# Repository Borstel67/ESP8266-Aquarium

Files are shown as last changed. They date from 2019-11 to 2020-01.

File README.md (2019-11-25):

# esp8266-Aquarium

Beschreibung Projekt

Mit diesem Projekt habe ich meine Aquarien Beleuchtung auf LED Umgestellt.

Die Aquarien Beleuchtungssteuerung basiert auf einem ESP8266 und einem WS2812b Led Strip.
Der ESP übernimmt dabei die Ansteuerung des Strips und beinhaltet den Webserver mit der Bedienoberfläche zur Anzeige der Zustände
und Konfiguration der Beleuchtung.

Funktionen:
-	WLAN
1.	Config Mode
2.	AP Mode
3.	STA Mode

-	Uhr
1.	Synchronisation mit NTP Server
2.	Zeitzonen Einstellung Uhr
3.	Manuelle Zeiteinstellung
4.	Sommer Winterzeit Umschaltung Uhr

-	Sonne und Mond
1.	Sonnenaufgangs und Sonnenuntergangs Berechnung
2.	Mondphasen Berechnung zur Ansteuerung eines Teiles des Strip für die Mondbeleuchtung

-	Steuerung
1.	Für jede 4te LED (4 Kanäle) kann eine andere Farbe für Tag und Nacht vorgewählt werden 
2.	Jeder Kanal hat zwei Schulzeiten 
3.	Die maximale Anzahl der des LED Strip kann eingestellt werden
4.	Für die Mondbeleuchtung können beliebige LED ausgewählt werden

-	Eingebundenen Protokolle
1.	Syslog
2.	FTP
3.	telnet

-	Konfiguration und Bedienung
1.	Die Konfiguration erfolgt über den Integrierten WEB- Server
2.	Die Konfigurationsdaten werden in einen JSON File auf dem ESP abgelegt.

Offen Punkte 
-	UDP Kopplung mehrerer ESP zur Ansteuerung weiteren Geräten wie CO2 Generator
-	HomeMatic Kopplung
-	MQTT Einbindung

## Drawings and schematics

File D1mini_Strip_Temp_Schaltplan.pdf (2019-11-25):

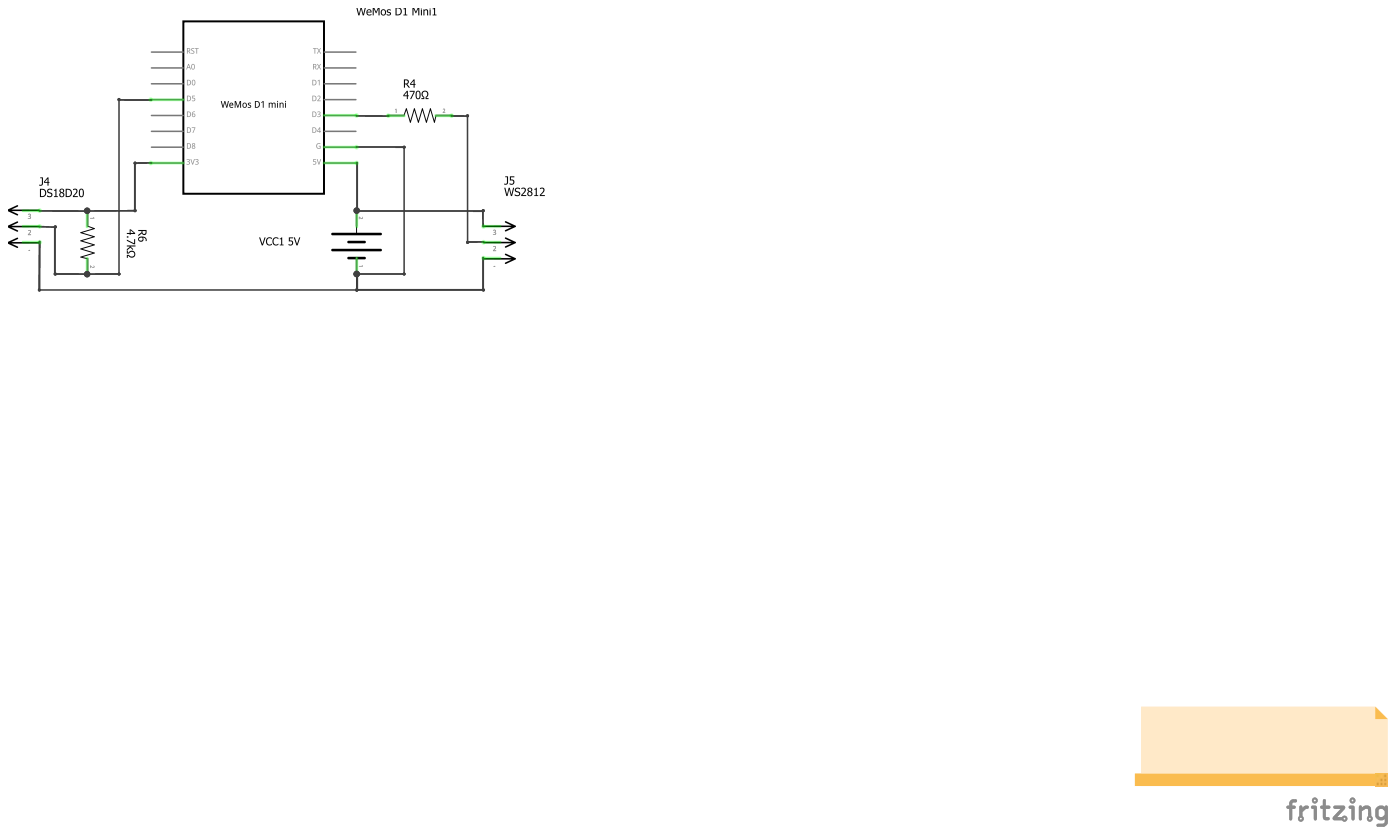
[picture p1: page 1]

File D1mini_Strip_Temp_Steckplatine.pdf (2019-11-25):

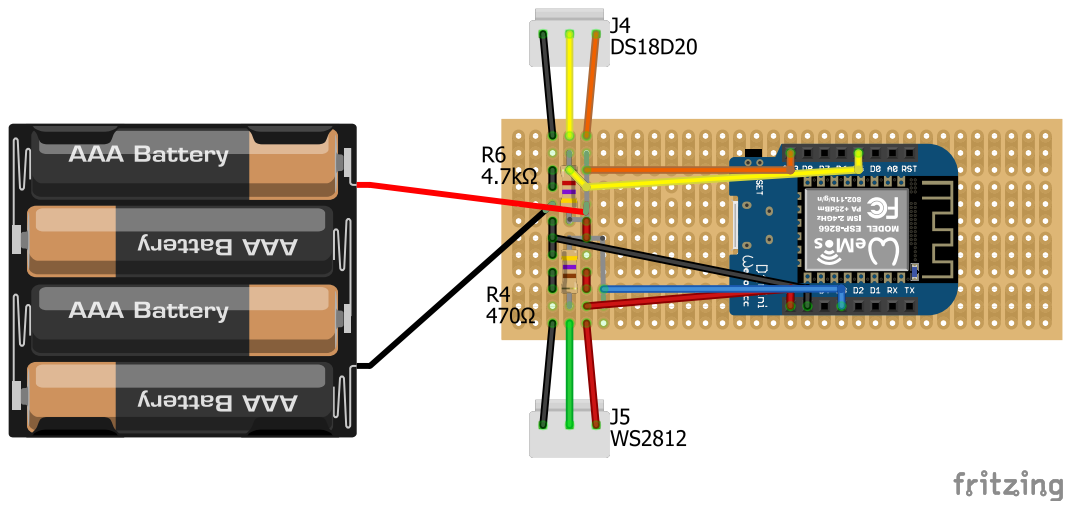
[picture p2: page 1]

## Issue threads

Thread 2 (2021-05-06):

RGB bzw BGR

Faabu, 2021-05-06:
Ist es möglich die Art des LED Strips zu ändern ?? Habe schon versucht das in der Aquarium .ino zu ändern,leider scheitert es beim kompillieren mit Arduino ide oder VC Code bei mir

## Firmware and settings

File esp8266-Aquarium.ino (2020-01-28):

/*
  ESP8266 Bibliotek 2.4.1
  ArduinoJson.h version 5
  Generic ESP8285 Module
  Flash Mode: DOUT
  Flash Frequency: 40 MHz
  CPU Frequency: 80 MHz
  Flash Size: 1M (64k SPIFFS)
*/

#define VARSIZE4				4
#define VARSIZE6				6
#define VARSIZE8				8
#define VARSIZE10				10
#define VARSIZE16				16
#define VARSIZE32	    		32
#define VARSIZE64	    		64
#define VARSIZE255	    		255


#define FASTLED_ALLOW_INTERRUPTS 0

#include <Arduino.h>
#include <FS.h>
#include <ArduinoJson.h>				// v.5.xx
#include <ESP8266WiFi.h>
#include <ESP8266FtpServer.h>
#include <ESP8266HTTPClient.h>
#include <ESP8266WebServer.h>
#include <ESP8266HTTPUpdateServer.h>
#include <ESP8266mDNS.h>
#include <uMQTTBroker.h>
#include <PubSubClient.h>
#include <sunMoon.h>
#include <Time.h>						// für NTP
#include <Timezone.h>					// sommer winterzeit
#include <TimeLib.h>					// für NTP und SunMoon
#include <ArduinoOTA.h>
#include <WiFiUdp.h>
#include <FastLED.h>
#include <OneWire.h>				// für Temperatur DS18B20
#include <DallasTemperature.h>		// für Temperatur DS18B20
#include "WM.h"
#include "css_global.h"
#include "js_global.h"
#include "js_webled.h"
#include "js_fwupd.h"

// definire Programmteile
// def Debug Serial ein und ausschalten
#define	LEDStrip // definierung wenn ein LEDStrip angeschlossen
//#define UDPDEBUG
#define SERIALDEBUG
#define TELNET

// definire Parameter 
#define MillisKeyBounce			100		//Millisekunden zwischen 2xtasten
#define ConfigPortalTimeout		180		//Timeout (Sekunden) des AccessPoint-Modus
#define HTTPTimeOut				1500	//Timeout (Millisekunden) für http requests
#define UDPPORT					6676	// UDP Port
#define KEYPRESSLONGMILLIS		1500	//Millisekunden für langen Tastendruck bei Sonoff Touch als Sender
#define MAX_TELNET_CLIENTS		2		// Telnet Server

const String FIRMWARE_VERSION = "1.3.5";


//FW über GITHUB
const char GITHUB_REPO_URL[] PROGMEM = "https://api.github.com/repos/jp112sdl/SonoffHMLOX/releases/latest";

//Debug Syslog über UDP
#ifdef UDPDEBUG
const char* SYSLOGIP = "192.168.178.100";
#define SYSLOGPORT          514
#endif
enum _SyslogSeverity {
	_slEmergency,
	_slAlert,
	_slCritical,
	_slError,
	_slWarning,
	_slNotice,
	_slInformational,
	_slDebug
};
// end Debug

//Auswahl Homatic Loxon
enum BackendTypes_e {
	BackendType_HomeMatic,
};

enum TransmitStates_e {
	NO_TRANSMITSTATE,
	TRANSMITSTATE
};

// Golbal Config schreiben in Datei jonson.conf
struct globalconfig_t {
	char ledcolor1[VARSIZE8] = "#ffffff";				// Color Kanal 1 Ein
	char ledcolor2[VARSIZE8] = "#ffff00";				// Color Kanal 2 Ein
	char ledcolor3[VARSIZE8] = "#ccff00";				// Color Kanal 3 Ein
	char ledcolor4[VARSIZE8] = "#ffa200";				// Color Kanal 4 Ein
	char ledcolor5[VARSIZE8] = "#000000";				// Color Kanal 1 Aus
	char ledcolor6[VARSIZE8] = "#000000";				// Color Kanal 2 Aus
	char ledcolor7[VARSIZE8] = "#000000";				// Color Kanal 3 Aus
	char ledcolor8[VARSIZE8] = "#000000";				// Color Kanal 4 Aus
	char ledcolormoon[VARSIZE8] = "#000000";			// Color bei Mond
	char time1[VARSIZE6] = "06:30";						// Zeit Kanal 1 Ein
	char time11[VARSIZE6] = "00:00";					// Zeit Kanal 1 Ein
	char time2[VARSIZE6] = "06:45";						// Zeit Kanal 2 Ein
	char time21[VARSIZE6] = "00:00";					// Zeit Kanal 2 Ein
	char time3[VARSIZE6] = "06:15";						// Zeit Kanal 3 Ein
	char time31[VARSIZE6] = "00:00";					// Zeit Kanal 3 Ein
	char time4[VARSIZE6] = "06:30";						// Zeit Kanal 4 Ein
	char time41[VARSIZE6] = "00:00";					// Zeit Kanal 4 Ein
	char time5[VARSIZE6] = "21:00";						// Zeit Kanal 1 Aus
	char time51[VARSIZE6] = "00:00";					// Zeit Kanal 1 Aus
	char time6[VARSIZE6] = "21:00";						// Zeit Kanal 2 Aus
	char time61[VARSIZE6] = "00:00";					// Zeit Kanal 2 Aus
	char time7[VARSIZE6] = "21:30";						// Zeit Kanal 3 Aus
	char time71[VARSIZE6] = "00:00";					// Zeit Kanal 3 Aus
	char time8[VARSIZE6] = "21:45";						// Zeit Kanal 4 Aus
	char time81[VARSIZE6] = "00:00";					// Zeit Kanal 4 Aus
	char hk1[VARSIZE4] = "2";							// Hand Kanal 1 (0=Aus/1=Ein/2=Uhr)
	char hk2[VARSIZE4] = "2";							// Hand Kanal 2 (0=Aus/1=Ein/2=Uhr)
	char hk3[VARSIZE4] = "2";							// Hand Kanal 3 (0=Aus/1=Ein/2=Uhr)
	char hk4[VARSIZE4] = "2";							// Hand Kanal 4 (0=Aus/1=Ein/2=Uhr)
	char hkm[VARSIZE4] = "2";							// Hand Kanal M (0=Auto/1=Ein/2=Uhr)
	char ledanzges[VARSIZE4] = "221";					// Anzahl LED in Strip
//	char ledanzges[VARSIZE4] = "76";					// Anzahl LED in Strip
	char ledanzmond[VARSIZE255] = "37-48;67-78;107-118";// Anzahl der mond led
//	char ledanzmond[VARSIZE255] = "54-56";              // Anzahl der mond led
	char ledanzcol[VARSIZE4] = "4";						// Anzahl der Collorkanäle
	char latitude[VARSIZE10] = "50.92878";				// Jena cordinates
	char longtitude[VARSIZE10] = "11.5899";
	//char DevicAPName[VARSIZE32] = "AP_TEST";			// Name des Access Point
	byte BackendType = BackendType_HomeMatic;			// definierung des Aussehens der HTML Seiten
	String Hostname = "ESP56";
} GlobalConfig;

// Net Config
struct NetConfig_t {
	char ip[VARSIZE16] = "192.168.178.251";				// IP STA
	char netmask[VARSIZE16] = "255.255.255.0";			// Netzmaske STA
	char gw[VARSIZE16] = "192.168.178.1";				// Gateway STA
	char DNS1[VARSIZE16] = "192.168.178.1";				// DNS Server 1 STA
	char DNS2[VARSIZE16] = "0.0.0.0";					// DNS Server 2 STA
	char APip[VARSIZE16] = "0.0.0.0";					// IP des AP
	char APnetmask[VARSIZE16] = "0.0.0.0";				// Netzmaske AP
	char APgw[VARSIZE16] = "0.0.0.0";					// Gateway AP
	char ccuIP[VARSIZE16] = "";							// IP der CCU CuxD
	char DeviceName[VARSIZE32] = "TEST";				// Netzname des ESP (Hostname)
	char NTPSERVER[VARSIZE255] = "192.168.178.1";		// NTP Server
	char TIMEZONE[VARSIZE4] = "1";						// Zeitzone
	char swu[VARSIZE4] = "1";							// Sommer/Winter Umschaltung
	char ftp[VARSIZE4] = "0";							// FTP ein
	char SYSLOGIP[VARSIZE4] = "0";						// SYSLOGIP ein
	char Telnet[VARSIZE4] = "0";						// Telnet ein
	char DateMan[VARSIZE16] = "0";						// Datum Manuelle 
	char TimeMan[VARSIZE6] = "0";						// Zeit Manuelle 
} NetConfig;

struct lastState_t {
	char confMode[VARSIZE4] = "0";						// configmode aktivieren
} lastState;

// homeMatic Config
struct hmconfig_t {
	String ChannelName = "";
	String ChannelNameSender = "";
	char PowerVariableName[VARSIZE255] = "";
	char EnergyCounterVariableName[VARSIZE16] = "";
} HomeMaticConfig;

// Config Allg
const String bootConfigModeFilename = "bootcfg.mod";
const String lastStateFile = "laststat.json";
const String configJsonFile = "config.json";
const String NetconfigJsonFile = "Netconfig.json";
bool RelayState = LOW;
bool KeyPress = false;
bool startAPMode = false;
bool WiFiConnected = false;
unsigned long time_m = 0;
unsigned long time_mn = 0;
unsigned long LastMillisKeyPress = 0;
unsigned long TimerStartMillis = 0;
unsigned long KeyPressDownMillis = 0;
unsigned long TimerSeconds = 0;
unsigned long LastWiFiReconnectMillis = 0;
unsigned long previousMillis = 0;         // speichert wie viele Sekunden seit derletzten Änderung vergangen sind
unsigned long interval = 1000;            // Interval zwischen zwei Änderungen
unsigned long previousMillis_1 = 0;       // speichert wie viele Sekunden seit derletzten Änderung vergangen sind
unsigned long interval_1 = 1000;          // Interval zwischen zwei Änderungen
bool OTAStart = false;
bool UDPReady = false;
bool startWifiManager = false;
bool wm_shouldSaveConfig = false;
bool PRESS_LONGsent = false;
#define wifiManagerDebugOutput   true

//FastLED
//#define LED_STRIP_PIN			0		// pin WS2812 WeMos D1
#define LED_STRIP_PIN			3		// pin WS2812 NodeMCU 1.0 (ESP-12)
#define NUM_LEDS                300
#define LED_TYPE                WS2812
#define COLOR_ORDER             GRB
#define FRAMES_PER_SECOND       60
CRGB leds[NUM_LEDS];                    //Anzahl von LED des Strip
//#define NUM_LEDS 221 //192+139+86


// Time NTP
char ntpServerName[VARSIZE255] = "us.pool.ntp.org";
//char noNTP[VARSIZE16] = "";
char NTPStaus[VARSIZE32] = "";
int timeZone = 1;     // Central European Time
int intAktZeit, akt_hour, akt_minute, akt_second, offsetCEST;
time_t prevDisplay = 0; // when the digital clock was displayed
TimeChangeRule CEST = { "CEST", Last, Sun, Mar, 2, 60 };     //Central European Summer Time
TimeChangeRule CET = { "CET ", Last, Sun, Oct, 3, 0 };       //Central European Standard Time
Timezone CE(CEST, CET);
// end Time NTP

// SunMoon
sunMoon  sm;
int sm_latitude;
int sm_longtitude;
int sm_timezone;
uint32_t jDay;
byte mDay;
time_t sRise;
time_t sSet;
time_t s_date;
//end SunMoon

// WEB Server
ESP8266WebServer WebServer(80);
ESP8266HTTPUpdateServer httpUpdater;
// end WEB Server

// Telnet Server
WiFiServer TelnetServer(23);
WiFiClient TelnetClient[MAX_TELNET_CLIENTS];
// end TelNet Server

// FTP Server
FtpServer ftpSrv;   //set #define FTP_DEBUG in ESP8266FtpServer.h to see ftp verbose on serial
// end FTP Server

// UTP Protokoll
struct udp_t {
	WiFiUDP UDP;
	char incomingPacket[255];
} UDPClient;

// Temperatur DS18B20
// Data wire is plugged into pin D5 on the ESP8266 12-E - GPIO 14 (D5)
#define ONE_WIRE_BUS_PIN		14		// pin Temperatur DS18B20
#define DS18B20_Aufloesung		8		// auflösung Temperatur DS18B20
#define Anzahl_Sensoren_DS18B20	1		// Anzahl der angeschlossenen Sensoren - Mögliche Werte: '0','1','2'
DeviceAddress DS18B20_Adressen;
// Setup a oneWire instance to communicate with any OneWire devices (not just Maxim/Dallas temperature ICs)
OneWire oneWire(ONE_WIRE_BUS_PIN);// on pin (a 4.7K resistor is necessary)
DallasTemperature myDS18B20(&oneWire);
// end Temperatur DS18B20

void setup() {
	Serial.begin(115200);
	TM("\nESP " + String(WiFi.macAddress()) + " startet... (FW: " + String(FIRMWARE_VERSION) + ")");

	DEBUG(F("Config-Modus aktivieren? "));
	if (SPIFFS.begin()) {
		DEBUG(F("-> bootConfigModeFilename mounted file system"));
		if (SPIFFS.exists("/" + bootConfigModeFilename)) {
			File _File = SPIFFS.open("/" + bootConfigModeFilename, "r+");
			DEBUG(_File + " existiert", "setup()", _slInformational);
			startWifiManager = false;
			if (_File && _File.size()) {
				String content = String(char(_File.read()));
				DEBUG("bootConfigMode FileContent = " + content, "setup()", _slInformational);
				if (content == "1") {
					startWifiManager = (content == "1");
					DEBUG("Starte doWifiManager");
					doWifiManager();
				}
			}
			_File.print("0");
			DEBUG("-> " + bootConfigModeFilename + " existiert, starte Programm");
			_File.close();
			SPIFFS.end();
		}
		else {
			DEBUG("-> " + bootConfigModeFilename + " existiert NICHT setBootConfigMode");
			DEBUG("Starte setBootConfigMode");
			setBootConfigMode();
		}
	}
	else {
		Serial.println(F("-> Nein, SPIFFS mount fail!"));
	}
	//lade Projetinstellungen
	loadNetConfig();
	loadSystemConfig();
	loadlastState();
	DEBUG(F("Projetinstellungen geladen"));
	//
//Ab hier ist die Config geladen und alle Variablen sind mit deren Werten belegt!
	//
	//GlobalConfig.Hostname = String(NetConfig.DeviceName);

	//Starte Wifi 
	doWifiConnect();

	// beginn Dienste
	// WEB Server
	initWebServerHandler();
	httpUpdater.setup(&WebServer);
	WebServer.begin();
	// end WEB

	// OTA
	startOTAhandling();
	DEBUG("Starte UDP-Handler an Port " + String(UDPPORT) + "...");
	UDPClient.UDP.begin(UDPPORT);
	UDPReady = true;
	// end OTA

	// Start Telnet Server
	//Serial.println("Starting Telnet server");
	TelnetServer.begin();
	TelnetServer.setNoDelay(true);
	// end Telnet Server

	// Start FTP Server
	ftpSrv.begin("esp8266", "esp8266");   //username, password for ftp.  set ports in ESP8266FtpServer.h  (default 21, 50009 for PASV)
	// end FTP Server

	DEBUG(WiFi.hostname() + " - Boot abgeschlossen, SSID = " + WiFi.SSID() + ", IP = " + String(IpAddress2String(WiFi.localIP())) + ", RSSI = " + WiFi.RSSI() + ", MAC = " + WiFi.macAddress(), "Setup", _slInformational);
	// ende stat dienste

	// Time NTP
	void digitalClockDisplay();
	void printDigits(int digits);
	void sendNTPpacket(IPAddress & address);
	NTP_Set();
	// end NTP

	// config MQTT 
	char _buff[] = "";
	loadMqtt_set();
	// end config MQTT 

	// config HomeMatic CCU CuxD 
	CUxD_Set();
	// end config HomeMatic CCU CuxD 

	// Temperatr DS18B20
	TempDS18B20_Set();
	// end Temperatur DS18B20

	// SunMoon
	SunMmoon_Set();
	// end SunMoon

	//LED Strip
	FastLED_Set();	
	/*const int anzled = atoi(GlobalConfig.ledanzges);
	anzahl der led der kette FastLED.addLeds<WS2812, LED_STRIP_PIN, GRB>(leds, anzled).setCorrection(TypicalLEDStrip); */
	// end LED Strip

	//if (timeStatus() == timeNotSet) {
	//	TimeHand();
	//}
}

void loop() {
	//Überlauf der millis() abfangen
	if (LastMillisKeyPress > millis())
		LastMillisKeyPress = millis();
	if (TimerStartMillis > millis())
		TimerStartMillis = millis();
	if (LastWiFiReconnectMillis > millis())
		LastWiFiReconnectMillis = millis();

	//Reconnect WiFi wenn nicht verbunden (alle 30 Sekunden)
	if (!startAPMode) {
		if (WiFi.status() != WL_CONNECTED) {
			WiFiConnected = false;
			if (millis() - LastWiFiReconnectMillis > 30000) {
				LastWiFiReconnectMillis = millis();
				DEBUG("WiFi Connection lost! Reconnecting...");
				WiFi.reconnect();
			}
			// Setup MDNS responder
			if (!MDNS.begin(NetConfig.DeviceName)) {
				Serial.println("Error setting up MDNS responder!");
			}
			else {
				Serial.println("mDNS responder started");
				// Add service to MDNS-SD
				MDNS.addService("http", "tcp", 80);
			}
		}
		else {
			if (!WiFiConnected) {
				DEBUG("WiFi reconnected!");
				WiFiConnected = true;
			}
		}
	}

	//auf OTA Anforderung reagieren
	ArduinoOTA.handle();
	if (!OTAStart) {
		//eingehende UDP Kommandos abarbeiten
		String udpMessage = handleUDP();
		if (udpMessage == "bootConfigMode")
			setBootConfigMode();
		if (udpMessage == "reboot")
			ESP.restart();

		// telnet
		Telnet();
		// MQTT
		mqtt_loop();
		// FTP Server
		//ftpSrv.handleFTP();        //make sure in loop you call handleFTP()!!

		//eingehende HTTP Anfragen abarbeiten
		WebServer.handleClient();
		delay(10);
	}

	// Time NTP
	if (timeStatus() != timeNotSet) {
		if (now() != prevDisplay) { //update the display only if time has changed
			prevDisplay = now();
			digitalClockDisplay();
		}
	}

	// aufruf nach Zeit
	interval = 10000;
	if (millis() - previousMillis > interval) {
		previousMillis = millis();   // aktuelle Zeit abspeichern
		// funktion ausführen
		Sunrise();
		NTP_Set();
		NTPStatus();

	}
	interval_1 = 1000;
	if (millis() - previousMillis_1 > interval) {
		previousMillis_1 = millis();   // aktuelle Zeit abspeichern
		// funktion ausführen
		LEDSwitchK1();
		LEDSwitchK2();
		LEDSwitchK3();
		LEDSwitchK4();
		Serial.println("LED Swich end");
		LEDMoon();
		Serial.println("LED Moon end");
		TempDS18B20();
		Serial.println("LED Temp end");
	}
	// FTP Server
	ftpSrv.handleFTP();        //make sure in loop you call handleFTP()!!
}



//Timer
//    if (TimerSeconds > 0 && millis() - TimerStartMillis > TimerSeconds * 1000) {
//      DEBUG(F("Timer abgelaufen. Schalte Relais aus."), "loop()", _slInformational);
//      switchRelay(RELAYSTATE_OFF, TRANSMITSTATE);
//    }
//needed for UDP packet parser

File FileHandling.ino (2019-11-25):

// Globalconfig
#define JSONCONFIG_LEDCOLOR1              "ledcolor1"
#define JSONCONFIG_LEDCOLOR2              "ledcolor2"
#define JSONCONFIG_LEDCOLOR3              "ledcolor3"
#define JSONCONFIG_LEDCOLOR4              "ledcolor4"
#define JSONCONFIG_LEDCOLOR5              "ledcolor5" //neu
#define JSONCONFIG_LEDCOLOR6              "ledcolor6" //neu
#define JSONCONFIG_LEDCOLOR7              "ledcolor7" //neu
#define JSONCONFIG_LEDCOLOR8              "ledcolor8" //neu
#define JSONCONFIG_LEDCOLORMOON           "ledcolormoon" //neu
#define JSONCONFIG_TIME1                  "time1"
#define JSONCONFIG_TIME11                 "time11"
#define JSONCONFIG_TIME2                  "time2"
#define JSONCONFIG_TIME21                 "time21"
#define JSONCONFIG_TIME3                  "time3"
#define JSONCONFIG_TIME31                 "time31"
#define JSONCONFIG_TIME4                  "time4"
#define JSONCONFIG_TIME41                 "time41"
#define JSONCONFIG_TIME5                  "time5" //neu
#define JSONCONFIG_TIME51                 "time51"
#define JSONCONFIG_TIME6                  "time6" //neu
#define JSONCONFIG_TIME61                 "time61"
#define JSONCONFIG_TIME7                  "time7" //neu
#define JSONCONFIG_TIME71                 "time71"
#define JSONCONFIG_TIME8                  "time8" //neu
#define JSONCONFIG_TIME81                 "time81"
#define JSONCONFIG_HK1                    "hk1"
#define JSONCONFIG_HK2                    "hk2"
#define JSONCONFIG_HK3                    "hk3"
#define JSONCONFIG_HK4                    "hk4"
#define JSONCONFIG_HKM                    "hkm"
#define JSONCONFIG_ledanzges              "ledanzges"
#define JSONCONFIG_ledanzcol              "ledanzcol"
#define JSONCONFIG_ledanzmond             "ledanzmond"
#define JSONCONFIG_LATITUDE               "latitude" //neu
#define JSONCONFIG_LONGTITUDE             "longtitude" //neu
// netconfig
#define JSONCONFIG_IP                     "ip"
#define JSONCONFIG_NETMASK                "netmask"
#define JSONCONFIG_GW                     "gw"
#define JSONCONFIG_DNS1                   "DNS1"
#define JSONCONFIG_DNS2                   "DNS2"
#define JSONCONFIG_APIP                   "APip"
#define JSONCONFIG_APNETMASK              "APnetmask"
#define JSONCONFIG_APGW                   "APgw"
#define JSONCONFIG_CCUIP                  "ccuip"
#define JSONCONFIG_DEVICENAME             "devicename"
#define JSONCONFIG_NTPSERVER              "ntpserver" //neu
#define JSONCONFIG_TIMEZONE               "timezone" //neu
#define JSONCONFIG_ftp                    "ftp"
#define JSONCONFIG_swu                    "swu"
// last State
#define JSONCONFIG_CONFMode               "confmode"



// laden der Daten aus config.json
bool loadSystemConfig() {
	DEBUG(F("loadSystemConfig mounting FS..."), "loadSystemConfig()", _slInformational);
	if (SPIFFS.begin()) {
		DEBUG(F("loadSystemConfig mounted file system"), "loadSystemConfig()", _slInformational);
		if (SPIFFS.exists("/" + configJsonFile)) {
			DEBUG(F("loadSystemConfig reading config file"), "loadSystemConfig()", _slInformational);
			File _File = SPIFFS.open("/" + configJsonFile, "r");
			if (_File) {
				DEBUG(F("loadSystemConfig opened config file"), "loadSystemConfig()", _slInformational);
				size_t size = _File.size();
				std::unique_ptr<char[]> buf(new char[size]);
				_File.readBytes(buf.get(), size);
				DynamicJsonBuffer jsonBuffer;
				JsonObject& json = jsonBuffer.parseObject(buf.get());
				DEBUG("Content of JSON Config-File: /" + configJsonFile, "loadSystemConfig()", _slInformational);
				//#ifdef SERIALDEBUG
				json.printTo(Serial);
				Serial.println();
				//#endif
				if (json.success()) {
					Serial.println("\nJSON OK loadSystemConfig()");
					DEBUG("\nJSON OK", "loadSystemConfig()", _slInformational);
					((json[JSONCONFIG_LEDCOLOR1]).as<String>()).toCharArray(GlobalConfig.ledcolor1, VARSIZE8);
					((json[JSONCONFIG_LEDCOLOR2]).as<String>()).toCharArray(GlobalConfig.ledcolor2, VARSIZE8);
					((json[JSONCONFIG_LEDCOLOR3]).as<String>()).toCharArray(GlobalConfig.ledcolor3, VARSIZE8);
					((json[JSONCONFIG_LEDCOLOR4]).as<String>()).toCharArray(GlobalConfig.ledcolor4, VARSIZE8);
					((json[JSONCONFIG_LEDCOLOR5]).as<String>()).toCharArray(GlobalConfig.ledcolor5, VARSIZE8);//neu
					((json[JSONCONFIG_LEDCOLOR6]).as<String>()).toCharArray(GlobalConfig.ledcolor6, VARSIZE8);//neu
					((json[JSONCONFIG_LEDCOLOR7]).as<String>()).toCharArray(GlobalConfig.ledcolor7, VARSIZE8);//neu
					((json[JSONCONFIG_LEDCOLOR8]).as<String>()).toCharArray(GlobalConfig.ledcolor8, VARSIZE8);//neu
					((json[JSONCONFIG_TIME1]).as<String>()).toCharArray(GlobalConfig.time1, VARSIZE6);
					((json[JSONCONFIG_TIME11]).as<String>()).toCharArray(GlobalConfig.time11, VARSIZE6);
					((json[JSONCONFIG_TIME2]).as<String>()).toCharArray(GlobalConfig.time2, VARSIZE6);
					((json[JSONCONFIG_TIME21]).as<String>()).toCharArray(GlobalConfig.time21, VARSIZE6);
					((json[JSONCONFIG_TIME3]).as<String>()).toCharArray(GlobalConfig.time3, VARSIZE6);
					((json[JSONCONFIG_TIME31]).as<String>()).toCharArray(GlobalConfig.time31, VARSIZE6);
					((json[JSONCONFIG_TIME4]).as<String>()).toCharArray(GlobalConfig.time4, VARSIZE6);
					((json[JSONCONFIG_TIME41]).as<String>()).toCharArray(GlobalConfig.time41, VARSIZE6);
					((json[JSONCONFIG_TIME5]).as<String>()).toCharArray(GlobalConfig.time5, VARSIZE6);//neu
					((json[JSONCONFIG_TIME51]).as<String>()).toCharArray(GlobalConfig.time51, VARSIZE6);//neu
					((json[JSONCONFIG_TIME6]).as<String>()).toCharArray(GlobalConfig.time6, VARSIZE6);//neu
					((json[JSONCONFIG_TIME61]).as<String>()).toCharArray(GlobalConfig.time61, VARSIZE6);//neu
					((json[JSONCONFIG_TIME7]).as<String>()).toCharArray(GlobalConfig.time7, VARSIZE6);//neu
					((json[JSONCONFIG_TIME71]).as<String>()).toCharArray(GlobalConfig.time71, VARSIZE6);//neu
					((json[JSONCONFIG_TIME8]).as<String>()).toCharArray(GlobalConfig.time8, VARSIZE6);//neu
					((json[JSONCONFIG_TIME81]).as<String>()).toCharArray(GlobalConfig.time81, VARSIZE6);//neu
					((json[JSONCONFIG_HK1]).as<String>()).toCharArray(GlobalConfig.hk1, VARSIZE4);//neu
					((json[JSONCONFIG_HK2]).as<String>()).toCharArray(GlobalConfig.hk2, VARSIZE4);//neu
					((json[JSONCONFIG_HK3]).as<String>()).toCharArray(GlobalConfig.hk3, VARSIZE4);//neu
					((json[JSONCONFIG_HK4]).as<String>()).toCharArray(GlobalConfig.hk4, VARSIZE4);//neu
					((json[JSONCONFIG_LEDCOLORMOON]).as<String>()).toCharArray(GlobalConfig.ledcolormoon, VARSIZE8);//neu
					((json[JSONCONFIG_HKM]).as<String>()).toCharArray(GlobalConfig.hkm, VARSIZE4);//neu
					((json[JSONCONFIG_ledanzges]).as<String>()).toCharArray(GlobalConfig.ledanzges, VARSIZE4);//neu
					((json[JSONCONFIG_ledanzcol]).as<String>()).toCharArray(GlobalConfig.ledanzcol, VARSIZE4);//neu
					((json[JSONCONFIG_ledanzmond]).as<String>()).toCharArray(GlobalConfig.ledanzmond, VARSIZE255);//neu
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

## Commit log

2019-12-18 Update LEDStrip
2020-01-28 Änderungen in der Ansteuerung Strip Moon
